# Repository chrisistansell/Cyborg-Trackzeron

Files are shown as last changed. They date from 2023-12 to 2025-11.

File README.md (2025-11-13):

Where we are now, as we approach 2026. 

Azeron Discord: Modifications Section.  I've invested a lot of time in the projects since this creation.  I enjoy working with the community to make their controller better.  Please take some time to visit there and make use of what you can find there.

Etsy Storefront:  [Coaleyed Gaming: Etsy Storefront](https://www.etsy.com/shop/CoaleyedGaming?ref=dashboard-header)
 
 - Standalone Trackball is available on this platform as static bearings and BTU driven motion.
 - Common modifications of pull and flick keys are available as well as my modded rails for the controller.
 - Up and coming items include several planned mods for Cyborg 2 controllers as well as the Keyzen.
 - In the case of special requests (through discord) I have made a mod for the trackball to convert the Cyro.
 - At some point the next big plan is to sacrfice the index and middle towers to work on a finger driven trackball, hopefully I can revive the 55mm huge trackball in this journey.
    
Since there is a lot of open source here, this project has been set to complete by me.  I've even went through the code in 2025 to clean it up and catch the formating up with all the QMK changes.

This Readme is coutesy of MK's main Trackzeron GitHub project.  A special thanks to his inspiration.  This will forever be linked to his OG mod of the Azeron Classic as a fork.

Reference site for any of my 3D designs for the Azeron controller (and some Keychron stuff) can be found here: [Thingiverse|Coaleyed](https://www.thingiverse.com/coaleyed/designs)

Please note that due to angles of the sensor in the design, you will need to use software such as [rawaccel](https://github.com/a1xd/rawaccel) or your on scripts to set the rotation between 10-15%.  Otherwise you will get a down pitch to the left on mouse movement.

# TRACKzeron: Adding trackball functionality to the [Azeron Keypad](https://www.azeron.eu/)

This repository contains source code and prebuilt firmware files for a modified Azeron keypad.

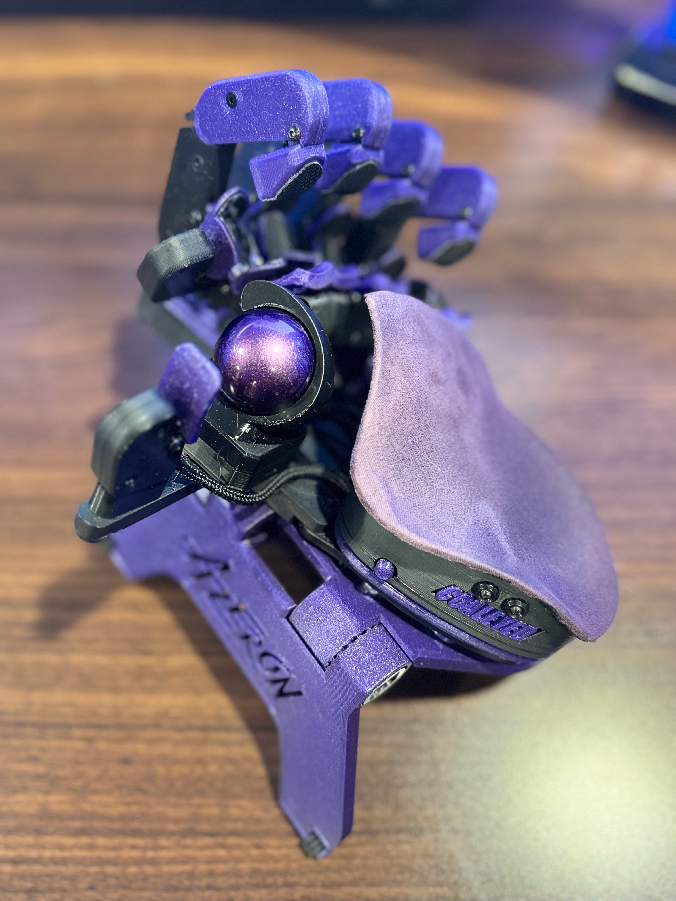
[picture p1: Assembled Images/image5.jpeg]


Side profile design.

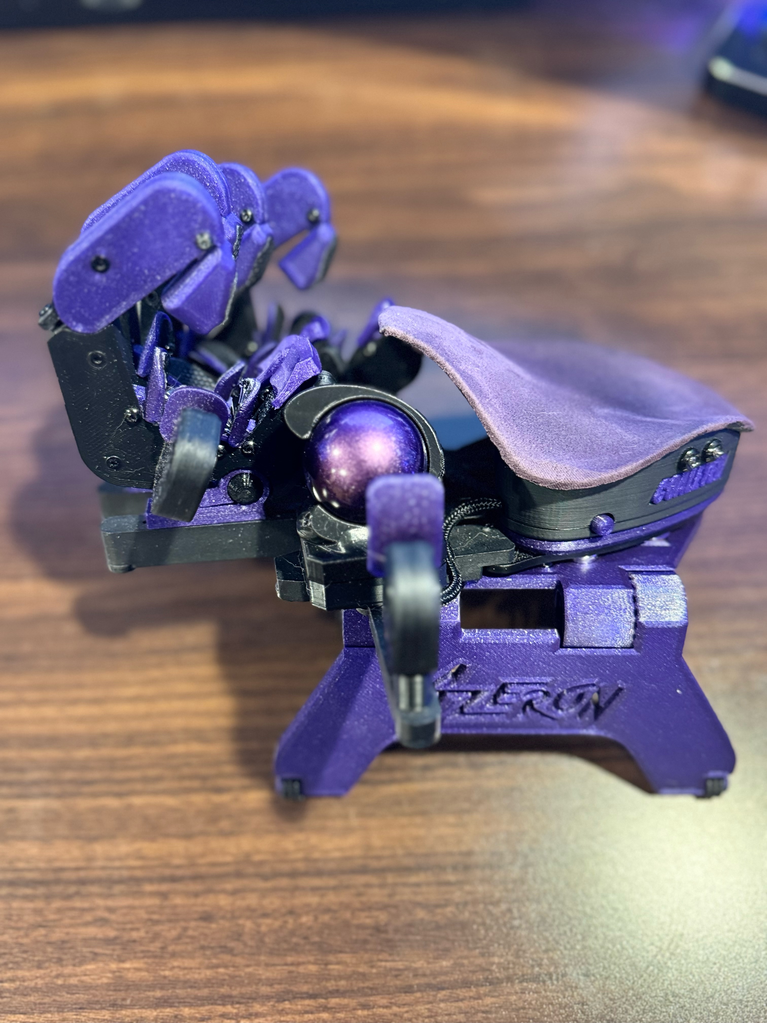
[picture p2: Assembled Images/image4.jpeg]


Angled profile.

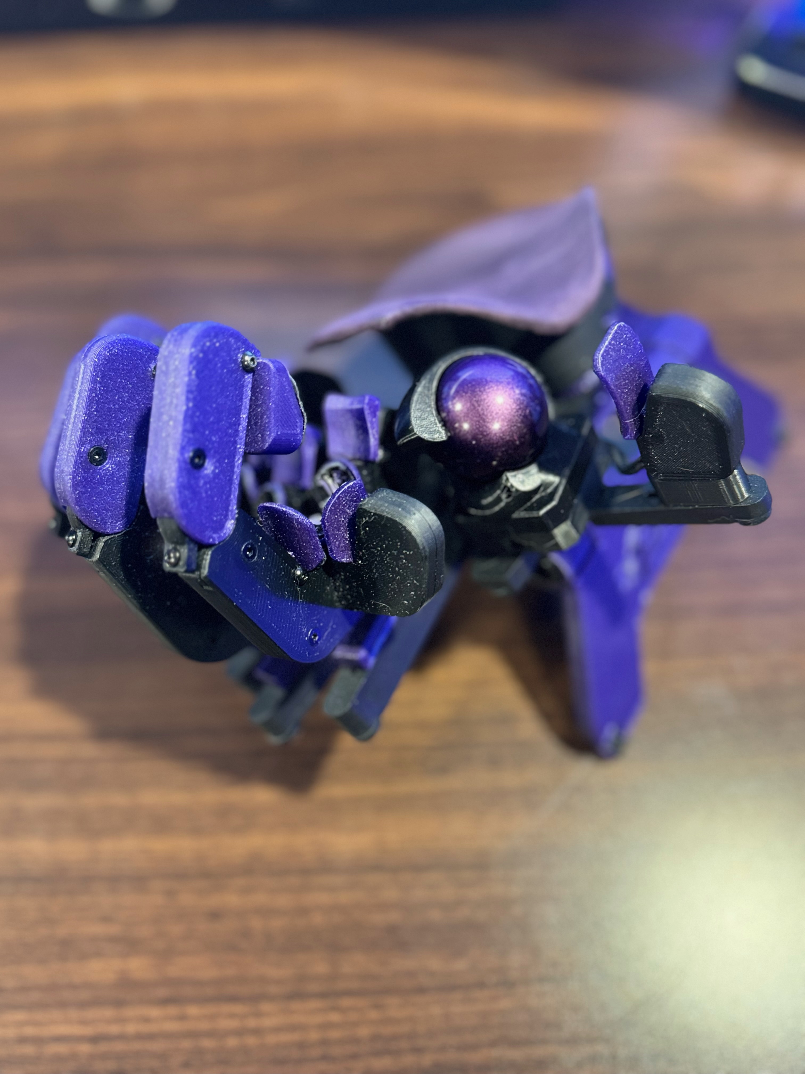
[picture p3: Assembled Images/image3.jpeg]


## Only for Classic, Compact, and Cyborg models with TEENSY++ 2.0 mainboards

**This does not work with the current Cyborg/Cyborg compact models with the black proprietary microcontroller.** It is for Azeron devices that use the Teensy++ 2.0 (green) mainboard. The Teensy++ 2.0 was discontinued in 2021, and Azeron started producing models with their proprietary ARM/STM32-based (black) mainboard in late-2022. Before making this modification make sure you have ordered a board with a Teensy++ 2.0 PCB.  This is not directly available on their website and you will have to special request it.  A Teensy++ 2.0 board can be purchased secondary market, you will probably want to purchase a terminal block with screw mounts to make it more connection friendly.

Additional testing will be performed on STM and RP2040 over the next few months.  I'll keep you guys updated.  If I can migrate to STM then we could potentially get 1000Hz polling rates.

## Notes

-   This mod has no official Azeron support.
-   I had to compile custom firmware to make the trackball work, so this modded keypad does not work with the official Azeron software.
-   This mod requires soldering. (No soldering to anything on the keypad, just the sensor module)   
-   Modifying your device always comes with risk attached. I’m sharing what worked for me and offer no guarantees.

## FAQs:

### “TRACKzeron”?
Trackball + Azeron = TRACKzeron.

### Will this work on my device with a black mainboard?
The firmware will not work. The new black mainboards have a different chip. The firmware was not designed for it. I cannot confirm whether the new mainboard can be rewired to accommodate the sensor.
-- Update 3.4.24 I'm working with Azeron to get the Azeron black microcontroller to see if I can push code to it.

### How did you add the trackball?
See the [guide](#guide).

### How does this work in the Azeron Software?
***This mod is not compatible with the official Azeron Software.*** You will need to use a different software to set your keybinds.  I have added support for VIA using the via.json file in the QMK folder.  VIAL is also an option, the files you need are all in keymap.c > VIAL.

You can optionally hard code your own keymaps and then create your own hex file.  This can be done by manipulating the the KC_xx entries found in the keymap.c folder.

### How do you use the Azeron Software with two keypads at once?
Since there is no thumbstick on this controller, the two together function like a keyboard and mouse.  You should be able to use both controllers without issues in games.

### Do you have a video where you’re playing with both keypads together?
Yes; there's a [YouTube clip](https://youtu.be/ogBYqxuF61s)  Sorry at the time I filmed this it was being done inverted by my camera.  I'll try to get an update to the video soon.

### Can you make me one?
No.  But I will gladly assist you in your build.  

## Guide

### Parts
- [Azeron Keypad](https://www.azeron.eu/) (Cyborg or Cyborg Compact with Teensy++ 2.0 green board)
- Teensy++ 2.0 Green Board AT90USB1286 - You might be able to find these on Aliexpress.  They will not have the terminal blocks so you will need to buy those seperately and will have to solder them on.  I was able to get everything to work.
	- It's end of support but still finding a few places like this that have the microcontroller [AliExpress Teensy 2.0++](https://www.aliexpress.us/item/2255800849800105.html?gatewayAdapt=glo2usa). 
	- I used 4 of these since I can't find a 20 pin version: [Screw Terminal Block Connectors](https://a.co/d/1D0JK94)
- [PMW3360 Motion Sensor](https://www.tindie.com/products/citizenjoe/pmw3360-motion-sensor/)
- [Trackzeron v4](https://github.com/chrisistansell/Cyborg-Trackzeron/blob/main/3D%20Print%20Models/Trackzeron%20v4%20-%20PTEG.stl) This is the model for the top half of the trackball holder.
- [Trackzeron Base v4](https://github.com/chrisistansell/Cyborg-Trackzeron/blob/main/3D%20Print%20Models/Trackzeron%20Base%20v4%20-%20PTEG.stl) This is the model for the bottom half of the trackball holder.

### Trackball Options
- 34mm Tackball: This could be a variety of trackballs on the market that fit the Logitech M570.  I personally tested color variant trackballs made by Perixx.  [Perixx PERIPRO-303 GBK 1.34"](https://www.amazon.com/dp/B08DD6GQRV?psc=1&ref=ppx_yo2ov_dt_b_product_details/)
	- I recently purchased a Protarc EM04 Wired Trackball and robbed it of it's 34mm purple trackball.

### Bearings
- Depending on your print choices, you will want to use either three (3) [3mm ceramic bearing balls](https://a.co/d/1juzp4G) or three (3) [3.5mm ceramic bearing balls](https://a.co/d/fikWqXD)
	- The most accurate trackball design is the lava lamp version.  I'd recommend this 3D print.  It uses 3mm bearings.

### Cabling (Optional if desoldering)
- [28 AWG wire](https://www.amazon.com/dp/B089Cq1C8L) You can reuse the wires going to the thumbstick if you like, you will likely need solder wick.  I recommend getting your own wire so you can revert your controller if needed.  Also good to have the wire so you can ground to the block rather than the teensy.
	- You could also use a terminal block with screw mounts to make connectivity easier. [8-pin 2.54mm Pitch PCB Terminal Block](https://www.amazon.com/dp/B098QLRFMF?ref=ppx_yo2ov_dt_b_product_details&th=1)
	- Using this will make it so you are unable to attach the shroud to the back to hide the sensor if you are using the simple v1/v2 3D print.
	- This will be hidden inside the "box" if you use v3 or v4 3D print.

### Hardware 
- 1 [M2.5 280pc Button Head Hex Screws](https://www.amazon.com/gp/product/B09CPDVYB7/ref=ppx_yo_dt_b_search_asin_title?ie=UTF8&psc=1)
	- To keep things simple, I'd suggest this set.  A lot cheaper than buying individual stuff and will have everything you need to do this project.
 	- Note that this comes with M2.5 hex nuts that you can use for the project. The next comment is optional if you buy this set.	
- Read above first! 2 [M2.5 thin hex nuts](https://www.mcmaster.com/products/hex-nuts/low-strength-steel-thin-hex-nuts-8/}) For the updated model.
	- I generally try to get everything from one place, but this was the only place I could find thin versions of the hex nuts.
- Optional [M2.5 square nuts](https://www.mcmaster.com/products/square-nuts/thread-size~m2-5/)
	- You don't need these, but could come in handy for projects you need to use M2.5 screws in customizations. 

### Tools
- screwdrivers: Azeron screwdriver with hex head, philips, and small flat head screwdriver to clean plastic from the 3D prints 
- precision tweezers
- soldering iron & solder 
	- wick is optional but helpful if you have soldering issues to undo
	- I also suggest a magnifying glass lamp and a heat proof working surface
- wire friendly scissors (i use Klein)
- wire stripper
- wire cutters

### Preparing

**NOTE:** It's important for the switches and sensor to be connected ***exactly as indicated*** or the device will not work.

- 3D print the trackball assembly.   
- Push the ceramic ball bearings into the trackball assembly.   
- Strip and tin 7-9 inches of 28 AWG hookup wire. Make sure you add 2-3 inches to the black wire to reach the grounding block.  You will need 6 wires.
- Solder wires to the PMW3360 sensor pins (The other two are not used):
	- GD 
	- SS    
	- SC
	- MO
	- MI    
	- VI

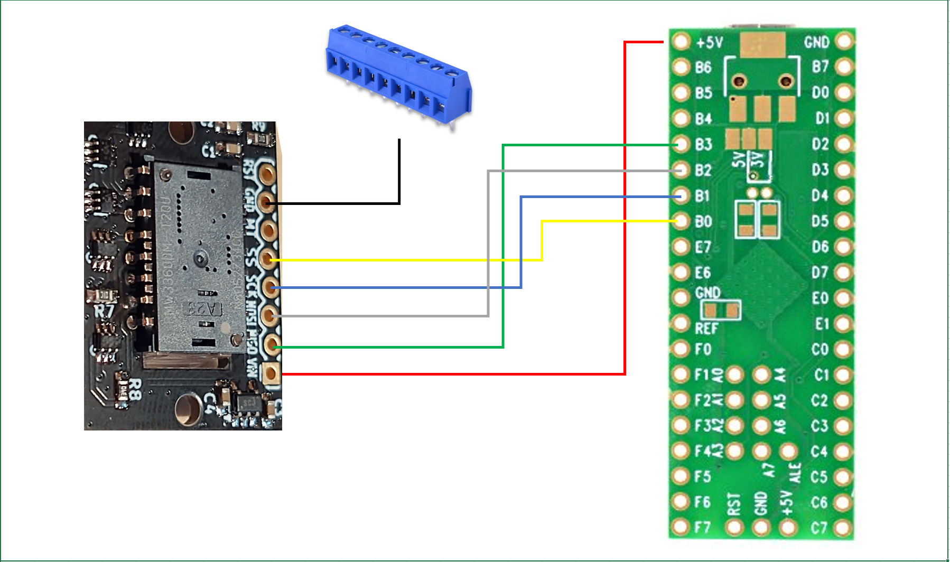
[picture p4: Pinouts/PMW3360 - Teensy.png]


### Rewire the Azeron (Cyborg/Cyborg Compact)

- Remove the Azeron palmrest to reveal the Teensy Board

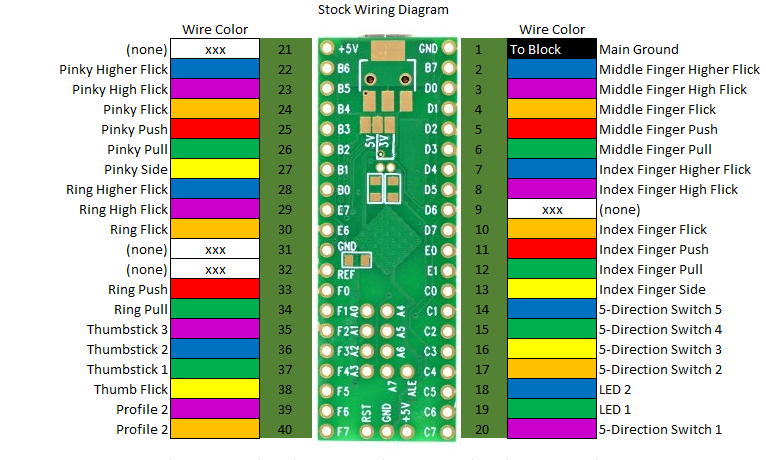
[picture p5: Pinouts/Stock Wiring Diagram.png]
Stock Wiring Diagram


- Disconnect all connections to the Teensy Board

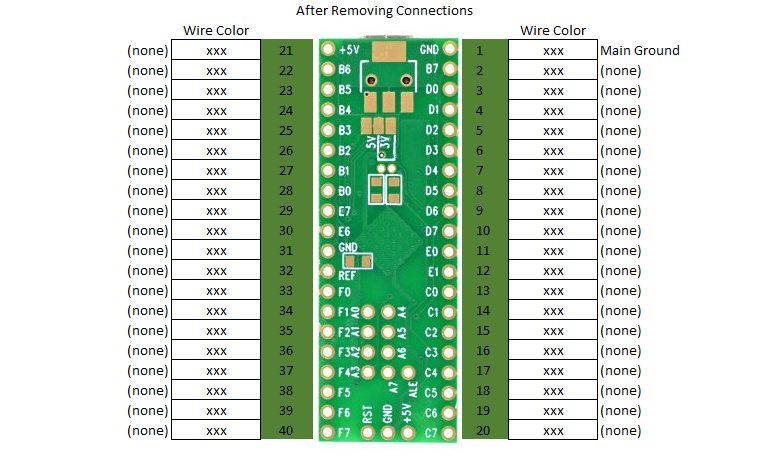
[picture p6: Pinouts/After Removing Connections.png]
After Removing Connections


- Reconnect the pinky and ring finger switches as follows:
	- Pinky finger:
		- High Pull/blue wire: B6
		- Pull/magenta wire: B5
		- Push/orange wire: B4
		- Flick/red wire: E7
 		- High Flick/green wire: E6 
   		- Side Flick/yellow: F0
	- Ring finger:
 		- High Pull/blue wire: F1
   		- Pull/magenta wire: F2
		- Push/orange wire: F3
		- Flick/red wire: F4
  		- High Flick/green wire: F5
	- Middle finger:
		- High Pull/blue wire: B7
		- Pull/magenta wire: D0
		- Push/orange wire: D1
		- Flick/red wire: D2
		- High Flick/green wire: D3  
	- Index finger:
		- High Pull/blue wire: D4
		- Pull/magenta wire: D5
		- Push/orange wire: E0
		- Flick/red wire: E1
		- High Flick/green wire: C0
		- Side Flick/yellow: C1
	- Thumb:
 		- Thumb side flick/yellow wire: C2
	- Profile switch:
 		- Profile 2/magenta wire: F6
   		- Profile 1/orange wire: F7
	- LED:	
 		- LED 2/green wire: C5
  		- LED 1/blue wire: C6

### Grounding your hardware:
- GND 1(Pin 1 Right side) - Top View Mounted - Azeron Ground Block (this already exists default from Azeron)
- GND 2(Pin 31 Left side) - Top View Mounted - (Optional) This pin is unused but might be required if you have issues with sleep performance on your computer.
	- If sleep issues are encountered, a piece of cable needs to be added from this pin to the ground block.
	- Due to limited connectons and only having 1 open slot on the terminal block that was freed up by removing the thumbstick, you can twist the optical sensor (mouse) ground cable (GND) and this (pin 31) GND together/Azeron then place it in the open ground terminal slot.

### Connect the PMW3360 Sensor:
-   Connect the sensor to the Teensy board as follows:
	- GD: GND (please read Grounding your hardware section above)
   	- SS: B0
   	- SC: B1
   	- MO: B2
   	- MI: B3
   	- VI: +5V



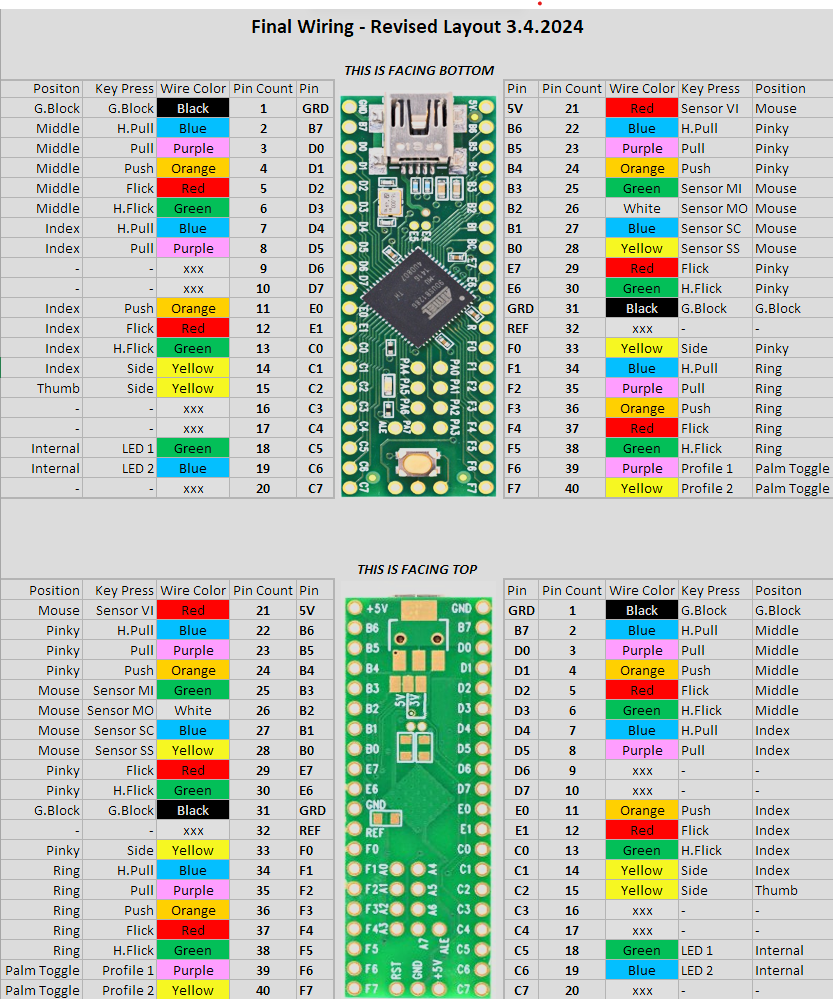
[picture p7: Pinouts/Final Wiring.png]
Final Wiring


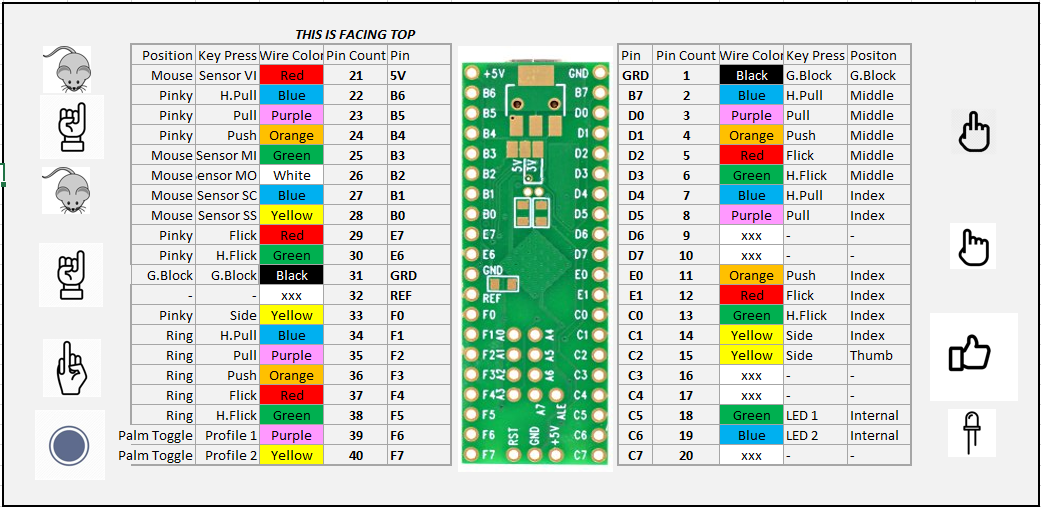
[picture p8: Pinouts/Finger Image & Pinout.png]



 
I used my own wiring for the optical sensor to the teensy board.  So I substituted the purple (magenta/pink) wire for a white wire because of the color spectrum in my wire kit.  I had USB connectivity issues where it would disconnect and reconnect when I used a ground wire from optical sensor to the teensy board.  I ended up moving the ground wire from the optical sensor to the grounding block in the palm rest.  

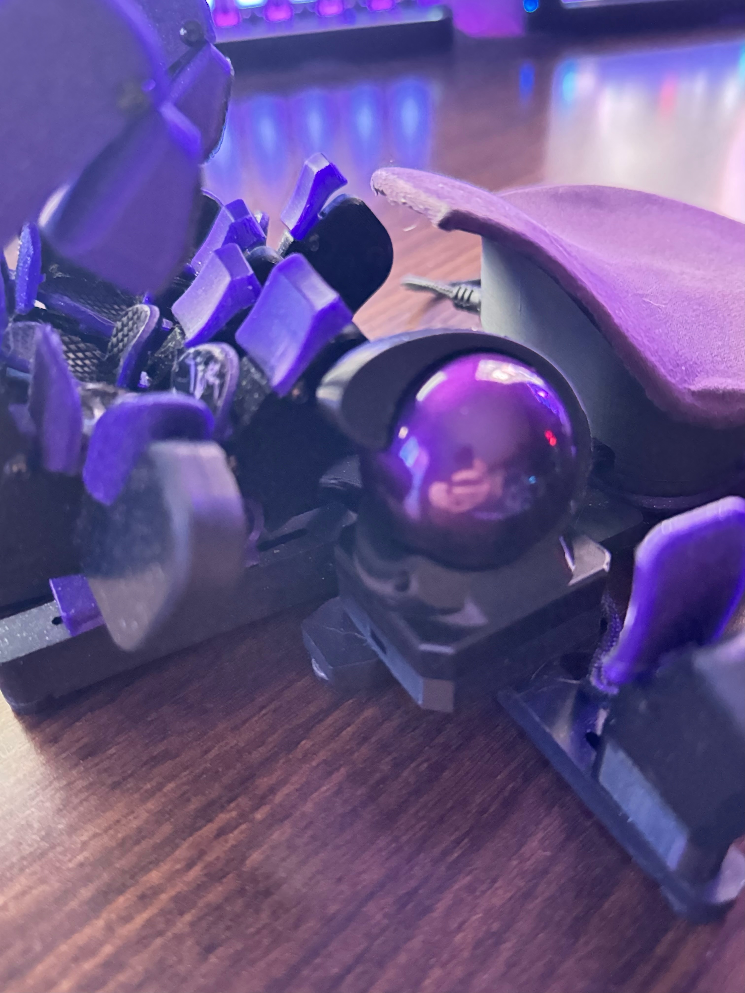
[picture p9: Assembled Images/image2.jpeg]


- Using firm force (can be assisted with outside pressure i.e., small channel-locks) push (3) 3mm bearings into slots.
- Attach the sensor to the trackball assembly. 
- Fit the trackball assembly to the Azeron thumb rail.   
- Reattach the palmrest
- Place ball in cup.
- Load firmware HEX file using the [QMK Toolbox](https://github.com/qmk/qmk_toolbox) by choosing AT90USB1286 for the MCU then pointi to the cyborg_trackzeron_via.hex file then pressing the reset button on the underside of the controller.  If you check auto flash it will apply the .hex once you press the DFU button.  If you do not click it, then you will need to click the flash button in the QMK toolbox application.
	- Make sure that you have downloaded the drivers for QMK toolbox to work correctly! 
- Take a look at keymaps in [VIA](https://www.caniusevia.com/), make any changes that you would like using the via.json file in the root directry of QMK > Cyborg Trackzeron.  Take the time to make a second profile tied to the profile switch on the palm rest of your Cyborg.  FN key activates an additional layer on your keypad if you would like to map that somewhere in your layout on your controllers for additional controls.
- Tweak your cursor accuracy using [rawaccel](https://github.com/a1xd/rawaccel).

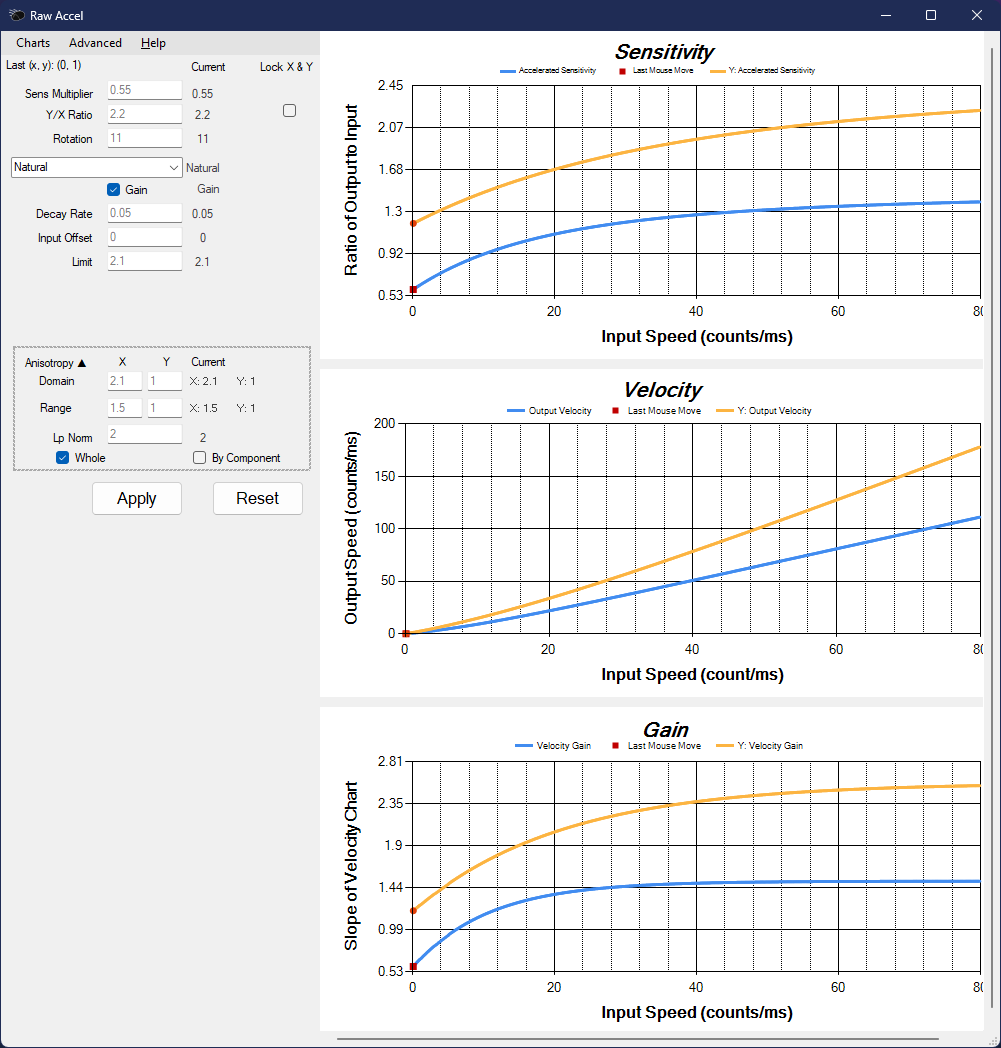
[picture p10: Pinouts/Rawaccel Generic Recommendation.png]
Recommended Generic Settings for Your Trackball


- Enjoy trackball keypad!

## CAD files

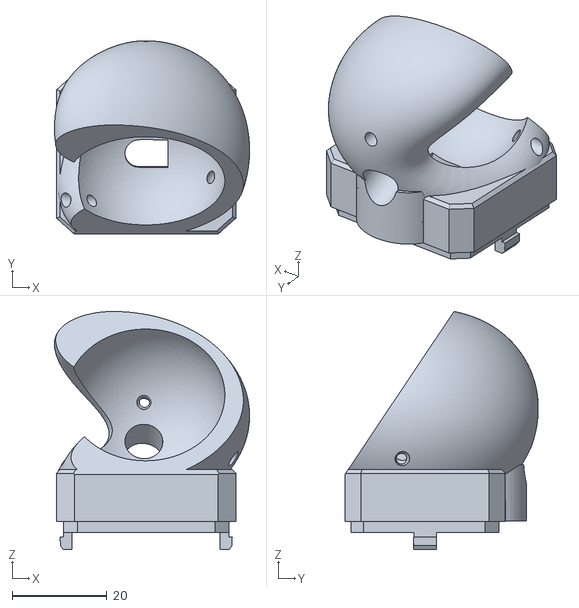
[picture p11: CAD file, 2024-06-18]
3D Print Models/Trackzeron v4 - PTEG.stl
41.3 x 40.9 x 50.3

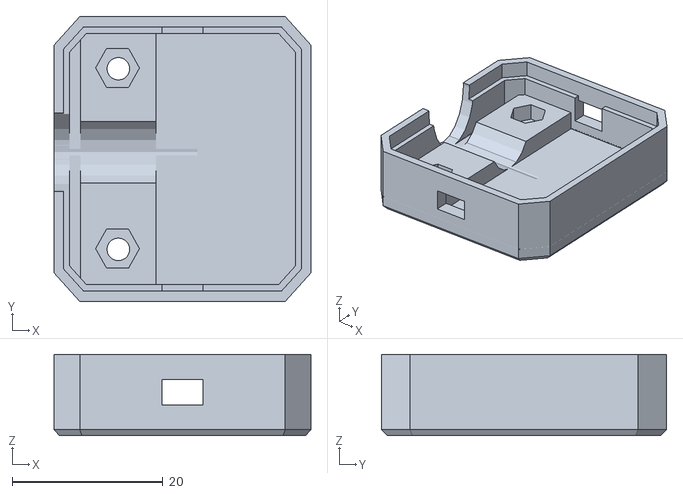
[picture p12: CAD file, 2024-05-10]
3D Print Models/Trackzeron Base v4 - PTEG.stl
34.0 x 37.7 x 10.8

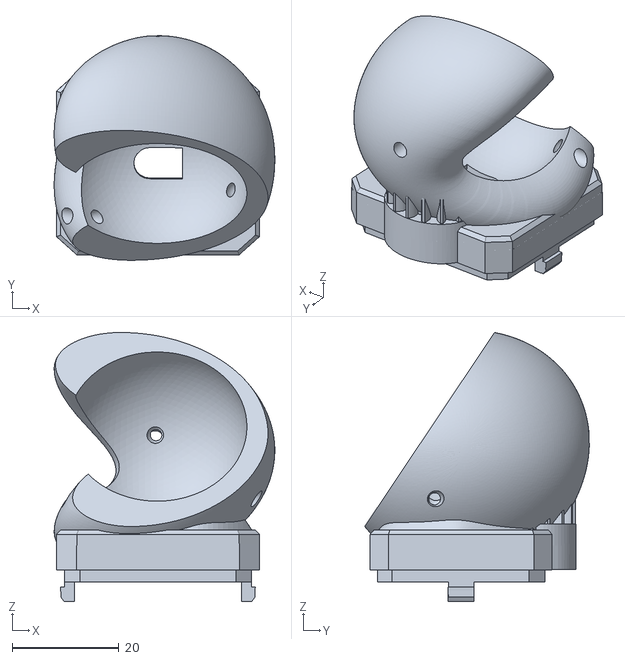
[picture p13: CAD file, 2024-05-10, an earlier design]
3D Print Files/Archives/34mm Lava Lamp Design STL v2/34.9mm Diameter - M575 & Perixx Trackball.stl
41.2 x 42.0 x 50.3

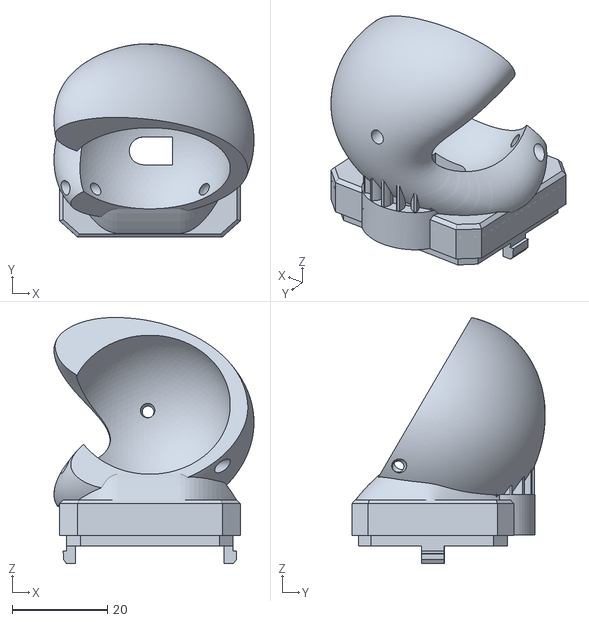
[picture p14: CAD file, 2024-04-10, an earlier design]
3D Print Files/Archives/34mm Lava Lamp Design STL/Lava Lamp 34mm-33 tilt-3mm.stl
42.0 x 40.6 x 51.7

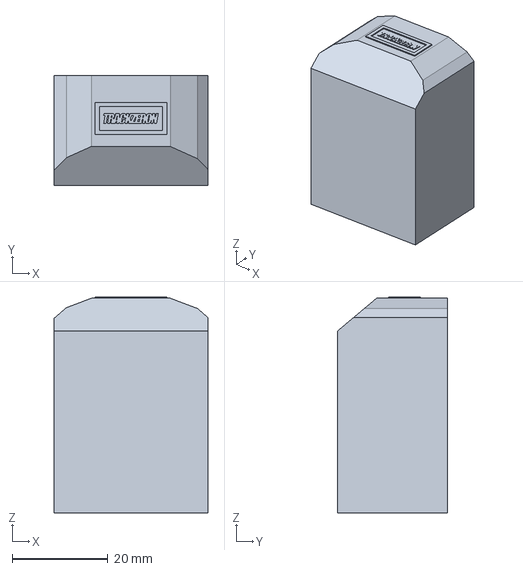
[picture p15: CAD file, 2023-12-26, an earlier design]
3D Print Files/Archives/3MF Files - 34mm/42_35_34mm v2 sensor & Back Shroud.3mf
32.0 x 23.0 x 45.0 mm

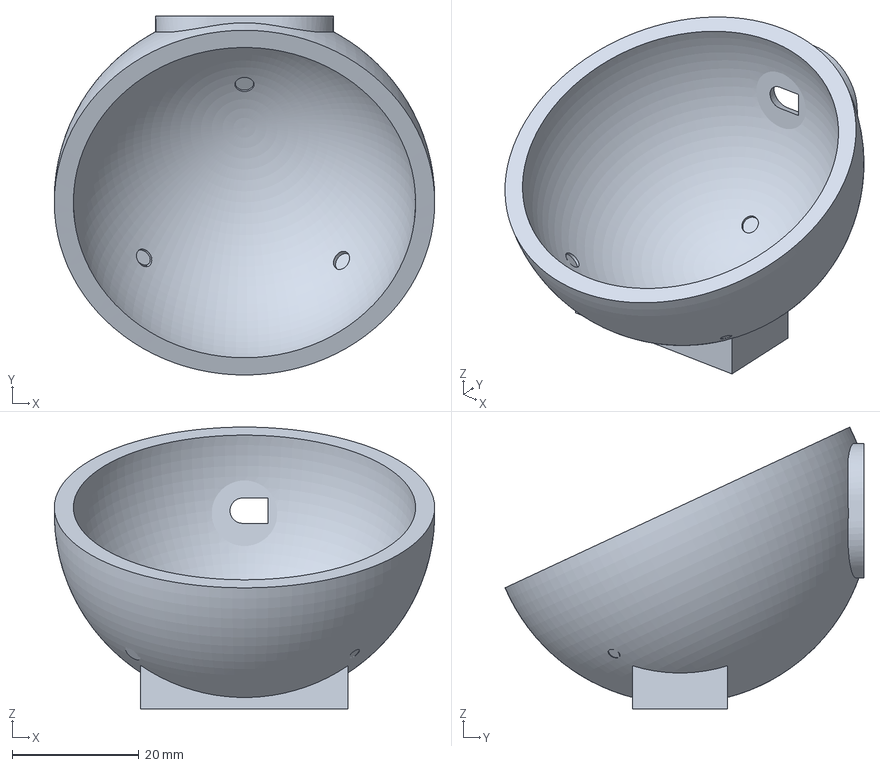
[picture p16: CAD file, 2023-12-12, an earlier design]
3D Print Files/Archives/3MF Files - 52mm/52mm Trackball Bearing Hole Shift.3mf
60.0 x 56.6 x 44.4 mm

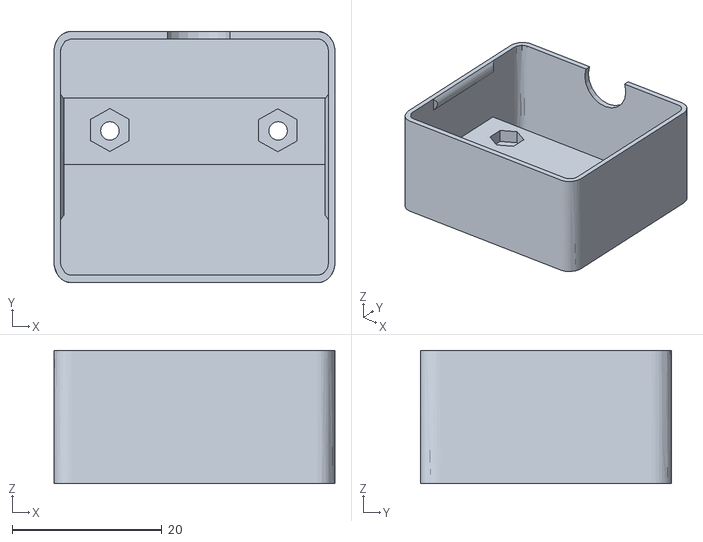
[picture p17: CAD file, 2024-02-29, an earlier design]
3D Print Files/Archives/STL Files - 34mm V2 Snap Fit/Trackball_18mm_base v2.stl
37.5 x 33.6 x 17.8

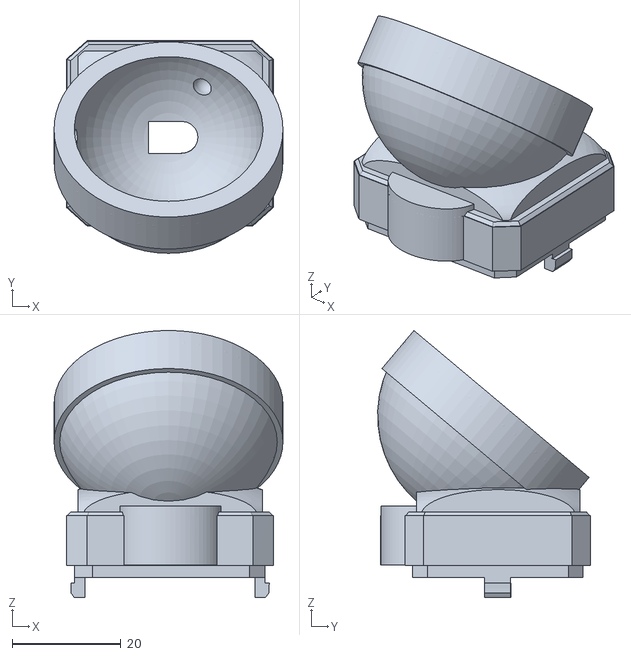
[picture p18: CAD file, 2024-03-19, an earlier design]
3D Print Files/Archives/STL Files - 34mm V3 Snap Fit/Final_use_3.5mm_bearings.stl
42.0 x 39.0 x 49.0

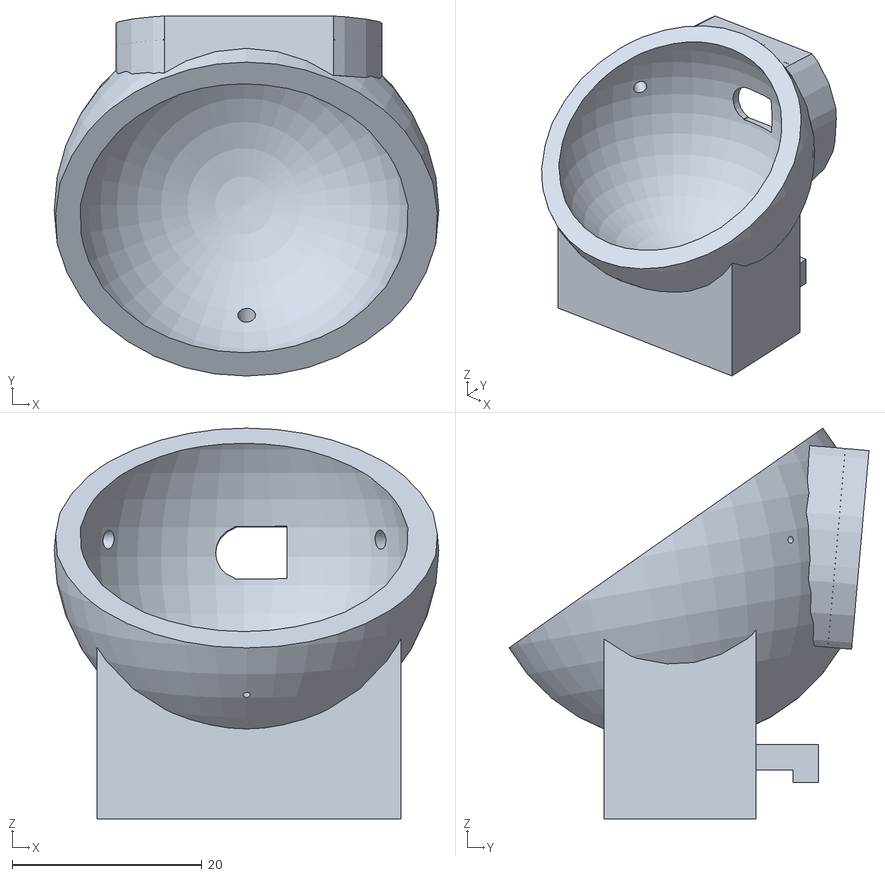
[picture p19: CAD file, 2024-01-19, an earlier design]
3D Print Files/Archives/STL Files - 34mm/40.5-35-34mm with hook.STL
40.5 x 37.9 x 41.1

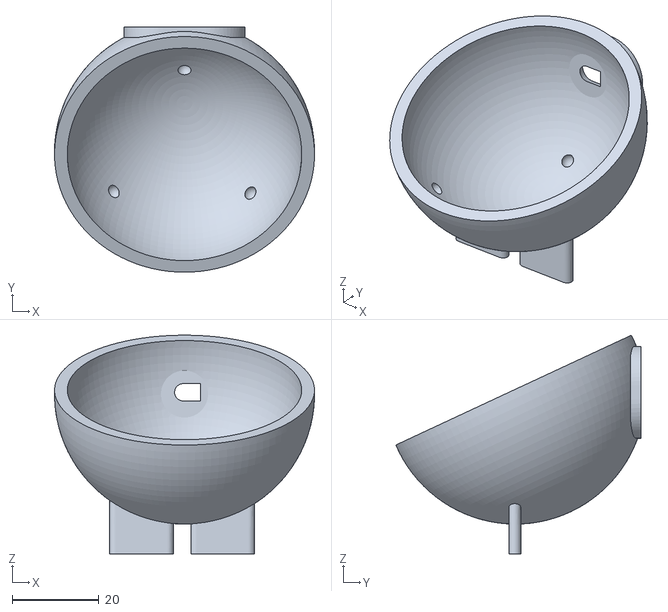
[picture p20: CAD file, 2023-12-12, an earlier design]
3D Print Files/Archives/STL Files - 52mm/Trackball_Holder.stl
60.0 x 56.6 x 50.4

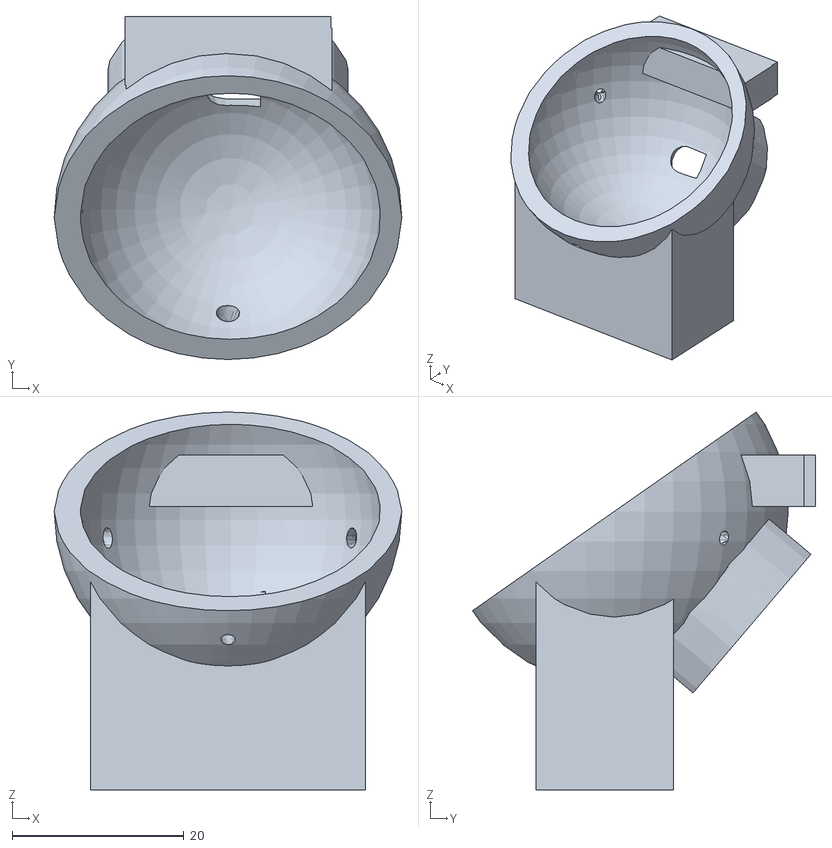
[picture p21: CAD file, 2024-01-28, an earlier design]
3D Print Files/Archives/34mm Files - For Angled Position for Terminal Block/34MM Angled Sensor - Term Block.stl
40.5 x 40.0 x 44.0

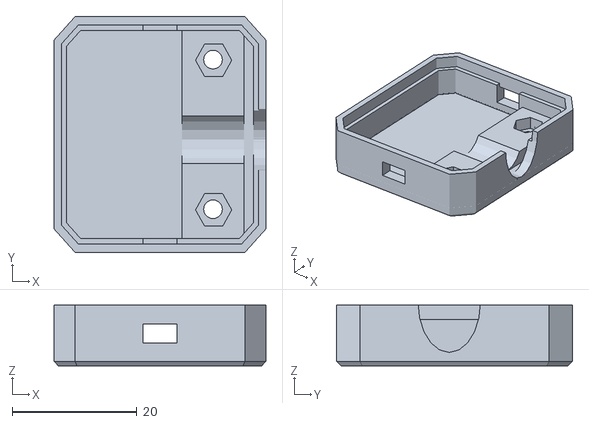
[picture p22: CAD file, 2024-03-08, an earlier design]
3D Print Files/Archives/34mm Lava Lamp Design STL/Bottom_-_Shorter.stl
34.0 x 37.9 x 9.72

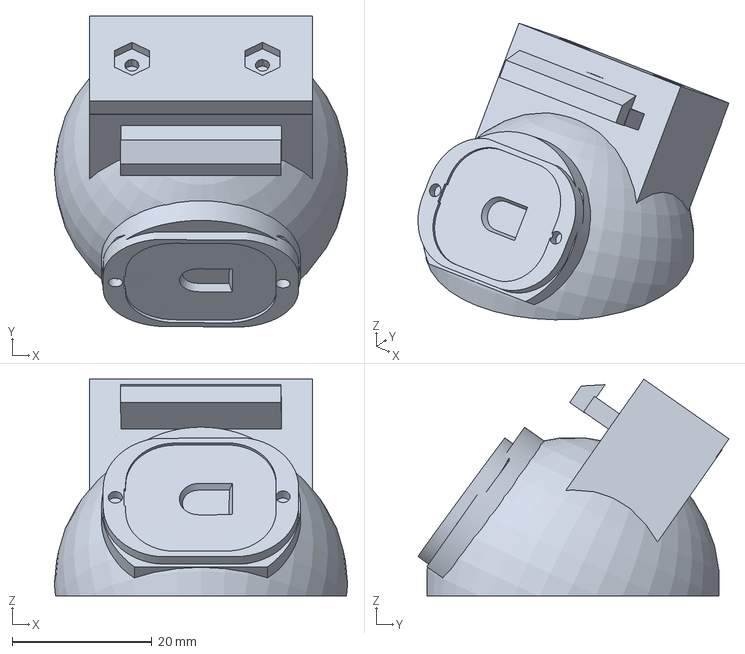
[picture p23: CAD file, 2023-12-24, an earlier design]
3D Print Files/Archives/3MF Files - 34mm/42_35_34mm v2 sensor clean.3mf
42.0 x 44.5 x 31.0 mm

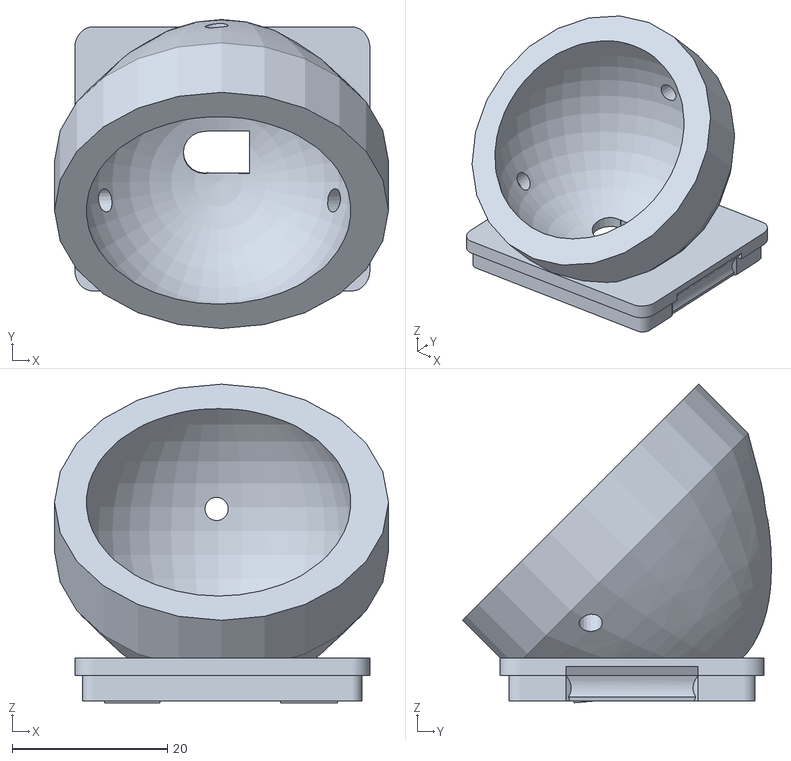
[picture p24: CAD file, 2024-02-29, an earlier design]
3D Print Files/Archives/STL Files - 34mm V2 Snap Fit/Trackball_Final_34mm-Top v2.stl
43.0 x 39.8 x 41.0

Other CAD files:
3D Print Files/Archives/34mm Lava Lamp Design STL v2/34.75mm Diameter - Proarc Trackball.stl
3D Print Files/Archives/STL Files - 34mm V3 Snap Fit/Final Top - Bearings 2 bottom 1 top.stl
3D Print Files/Archives/STL Files - 34mm/40.5-35-34mm no hook.STL
3D Print Files/Archives/34mm Files - For Angled Position for Terminal Block/Traclzeron Tagged Shroud - for term block cover.3mf
3D Print Files/Archives/34mm Files - For Angled Position for Terminal Block/Shroud 8mm & 25mm Screws needed - Term Block .stl
3D Print Files/Archives/34mm Lava Lamp Design STL v2/34.85mm Diameter.stl
3D Print Files/Archives/3MF Files - 34mm/42OD-36IDmm Trackzeron Clip and Shroud.3mf
3D Print Files/Archives/STL Files - 34mm V3 Snap Fit/Base.stl
3D Print Files/Archives/STL Files - 34mm V3 Snap Fit/Top-Lower Bearing Slots.stl
3D Print Files/Archives/STL Files - 34mm V3 Snap Fit/Top.stl
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

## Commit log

2023-12-07 Add files via upload
    This bracket can be printed to give you more wingspan to the thumb rail. You will need preferably flat head (2) 8mm/10mm and (1) 6mm screw with a 2.5mm hex or square nut to support the 3rd screw hole.
    [Reimagined - Bracket for Trackzeron Thumb.stl]
2023-12-12 Rename Cyborg Image with Large Billiard Ball. to 52mm Billiard Ball.jpeg
2024-02-19 Updated 2.18.24
    Added room to expand to configure LEDs and Profile Buttons.
2024-02-19 Delete Pinouts/Reconnecting Towers.png
    bad wiring diagram
2024-02-19 Delete Pinouts/Final Layout.png
    wrong wiring colors
2024-02-19 Updated Correct Wiring
    Added fixes for wiring as well as made Profile and LED functional. LEDs come on now by default dim lit.
2024-02-19 Updated Correction to Wiring Diagram
    Fixed profile locations as well as corrected colors. Added words for colors in case you might be color blind.
2024-02-19 Update README.md
    Fixed links to show a better version of the wiring diagram (fixed colors). Fixed location pinouts for Profile Switch.
2024-02-19 Update README.md
    Bearings section update
2024-02-19 Update README.md
    Added 25mm screw to list
2024-02-25 Update keymap.c
    Reflect Current Layout
2024-02-25 Update config.h
    Added pin support for profiles and LEDs
2024-02-25 Moved to .json and keymaps
    Huge rework of the code, as well as clean up. Changes made from the keymap level will create your new key assignments. Currently working on trying to get integration with VIA buy loading a via.json file. Having a hard time with the last step...
2024-02-29 New Version Created 2.28.2024
    This model clips together and gives space for wiring to rest in the base. Recommended that if you are using a terminal block attach it with wiring holes facing the center of the PMW3360/PMW3389. Works either way, but the fit is a little tight if you face it out and away from the center of the optical sensor.
    [Trackball_18mm_base v2.stl, Trackball_Final_34mm-Top v2.stl]
2024-03-02 The finish line for 3D work.
    Spent time getting bearing size down and getting the clips functioning properly.
    This is a nice snug fit with everything fitting nicely. You can either directly solder and have tons of space or use a terminal block (recommended). Watch your wires as you clip everything together!
    [Trackball Top - catch hook.stl, Trackball Top - grove in clip.stl, Trackball base.stl]
2024-03-04 Profiles were broken....
    Fixed DIP-switch-map section. Implemented its control into the LED & Profiles.
2024-03-04 Delete AzeronTrackballMod directory
    no longer working with arduino software
2024-03-04 Delete AzeronXimAlt-trackballmod directory
    No longer working with arduino .ino files.
2024-03-04 Delete 52mm Billiard Ball.jpeg
    completely migrated to 34mm trackball.
2024-03-05 Modified Keymaps to show visual reperesentaton
    This will help to match keys to locations on the controller. Flows naturally from top to bottom of the controller.
2024-03-11 Rotated Bearing Slots
    2 bottom 1 top
    [Final Top - Bearings 2 bottom 1 top.stl]
2024-03-19 Final Holder
    Until I try a revision. This one has proper angles for bearings and was finally able to get the cavities deep enough to hold the 3.5mm bearings. They can be pushed in with your thumb now. Should be a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
    [Final_use_3.5mm_bearings.stl]
2024-05-10 Update README.md
    Pointed to new STL files created in May 2024
2024-05-13 Update README.md
    Updated pin 31 GND comments under GND 1 section in the pinouts.
2024-05-13 Update README.md
    Re-numbered GND to more accurately reflect location on the board using pinout number as reference.
    Updated location names and moved around comment sections.
2024-05-13 Update README.md
    Removed old wiring diagram for PMW3360 - Teensy
2024-05-13 Update README.md
    Fixed row issues in Connect the PWM3360 Sensor: section
2024-05-13 Update README.md
    Removed extra section for PMW3360 to Teensy
2024-05-13 Update README.md
    Reworded GND to Grounding your hardware:
    Rephrased details to clarify potential use of second ground on the Azeron controller.
2024-05-13 Update README.md
    Additional Fixes for Grounding section.
2024-05-13 Update README.md
    More restructuring on grounding section.
2024-05-13 Update README.md
    Updated comments on Connecting the PMW3360 Sensor:
2024-05-13 Update README.md
    Fixed tabbing on grounding section
2024-05-13 Update README.md
    Fixed 3D Print Reference Link
2024-05-13 Update README.md
    Separated Grounding Section
2024-05-13 Update via.json
    Removed configurations for LED/PROFILE.
2024-06-18 Archived Older 3D Print Models
    [10.75mm 34mm 33.75mm Bottom.stl, 34.75mm Diameter - Proarc Trackball.stl, 34.85mm Diameter.stl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]
2025-10-23 Update keymap.c
    Cleaned up keymap.c. Took project down to 2 profiles. Can add this back in the future, but this was for migration purposes to get rid of the dip switch configurations.
2025-10-23 Update keymap.c
    Updated and removed layers. This was from me moving the dip switch configurations over to a button.
2025-10-23 Update keymap.c
    Removed the layers for testing when rebuilding configurations to remove dip switch configurations. This can be re-added in the future.
2025-10-23 Update rules.mk
    Removed dip switch from code.
2025-10-23 Update trackzeron.c
    Large overhaul to get rid of dip switch configuration and make profile swapping work. Swapping profiles was broken in last revision.
2025-10-23 Update trackzeron.h
    Removed code that wasn't needed. Added room for EEPROM to hold last state of hardware. If you power is lost it will return back in profile 2 versus resetting back to profile 1.
2025-10-29 Fix Sleep Issues
    Hoped to fix wake computer, but teensy 2.0++ doesn't have enough power to wake up the computer when it's in suspend.
2025-11-03 Wake clean up and deprecated info.json
    Removed unused commands. Cleaned up old wake commands. Fixed new mouse button acronyms. Ported info.json to keyboard.json to follow new scheme.
2025-11-04 Added DPI Hardset
    Added DPI @ 900 DPI by default - About 10% decrease in speed
    Added On settings for Command and Console enable so I can troubleshoot in the future.
    Added pointing devices auto start true to make sure I get the cursor instantly.
2025-11-07 Updated to fix stuck key from wake
    Was getting stuck key presses from clicking a button on the Azeron before the system was awake.
    To fix it I added a host ready code block to make sure that inputs aren't recognized until the controller is active. Mouse movement or the first keypress wakes the HID.
2025-11-11 Added mention of C6 Pin
    Added code to give access to pin C6. Was trying to work with dimming features, but was unsuccessful. Kept the pin mentioned in the residual code.
2025-11-11 Defined pin C6
    Added always on code for C6
2025-11-11 VIA Layers - keymap.c work
    Added comment section to help visualize button layout if changing button assignments at code level.
    Added additional layers for toggle profile swapping.
    Simplified naming i code to match layers in VIA.
